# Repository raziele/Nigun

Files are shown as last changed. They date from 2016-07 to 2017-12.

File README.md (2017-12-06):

## Nigun (Melody)
RF down-converter for (but not only for) SDR

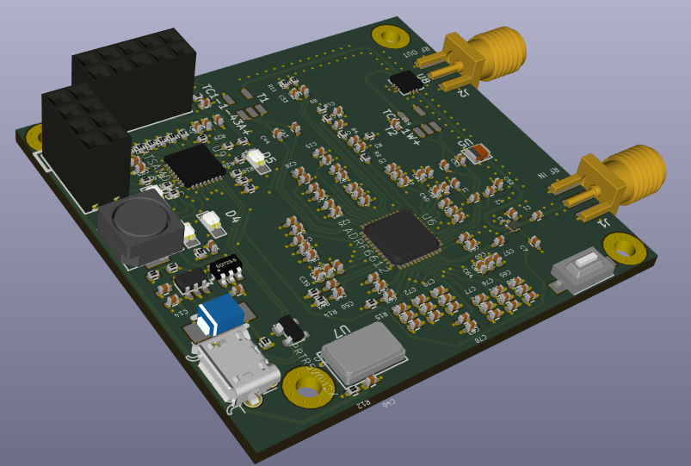
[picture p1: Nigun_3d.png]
NIGUN 3D model


## PURPOSE
Allow low-frequency SDR (mainly RTL-SDR) to recieve wireless signals in frequencies higher than 1500MHz
Nigun is platform-independant, so it can be paired with other devices such as YARD stick ONE and PandwaRF too!

## MAIN PROPERTIES
* Dynamic LO - LO will be determined by the user and programmed by the MCU
* Almost no filtering - will leave this challenge outside of this project scope
* Power up and programming via micro-usb connector. Should be able to power up from a USB power-pack (but probably not from a computer port)
* Highest RF frequency will be 3GHz
* Product also features a VCO for signal-generation purposes. VCO support should be 200-2700MHz

## DESIGN DETAILS
Can be found currently on http://slides.com/raziele/software-define-radio-4-5-6-7-8#/
All details should be updated here in the near future

## CURRENT STATUS
2017-05: Finished PCB design. Working on some finishing but I should order first batch during June

## CREDITS
* All those who were patient enough to teach, review, and answer my endless questions
* Michele Perla and his HACK project - for the Atmel SAMD21E reference design

## LICENSE
I haven't dealt with the licensing part yet, though it will probably be under CERN OHL v. 1.2.
For now, please contact me for any licensing request.

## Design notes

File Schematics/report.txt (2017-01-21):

Info: Reading netlist file "/Users/raziele/MyReps/Nigun/Schematics/Nigun.net".

Info: Using references to match components and footprints.

Info: Checking netlist component footprint "C1:/57E83FF1:Capacitors_SMD:C_0805_HandSoldering".

Info: Checking netlist component footprint "C2:/583F48BA:Capacitors_SMD:C_0805_HandSoldering".

Info: Checking netlist component footprint "C3:/583F48D7:Capacitors_SMD:C_0805_HandSoldering".

Info: Checking netlist component footprint "C4:/583F075F:Capacitors_SMD:C_0805_HandSoldering".

Info: Checking netlist component footprint "C5:/583F48C6:Capacitors_SMD:C_0805_HandSoldering".

Info: Checking netlist component footprint "C6:/57E9A56F:Capacitors_SMD:C_0805_HandSoldering".

Info: Checking netlist component footprint "C7:/57E843B4:Capacitors_SMD:C_0805_HandSoldering".

Info: Checking netlist component footprint "C8:/57E841A6:Capacitors_SMD:C_0805_HandSoldering".

Info: Checking netlist component footprint "C9:/583F083D:Capacitors_SMD:C_0805_HandSoldering".

Info: Checking netlist component footprint "C10:/584D4817:Capacitors_SMD:C_0805_HandSoldering".

Info: Checking netlist component footprint "C11:/583F48C0:Capacitors_SMD:C_0805_HandSoldering".

Info: Checking netlist component footprint "C12:/57E9A509:Capacitors_SMD:C_0805_HandSoldering".

Info: Checking netlist component footprint "C13:/583F0F91:Capacitors_SMD:C_0805_HandSoldering".

Info: Checking netlist component footprint "C14:/584FD6C7:Capacitors_SMD:C_0805_HandSoldering".

Info: Checking netlist component footprint "C15:/583F0F97:Capacitors_SMD:C_0805_HandSoldering".

Info: Checking netlist component footprint "C16:/57E9A3DC:Capacitors_SMD:C_0805_HandSoldering".

Info: Checking netlist component footprint "C17:/583F119E:Capacitors_SMD:C_0805_HandSoldering".

Info: Checking netlist component footprint "C18:/57E9A2BC:Capacitors_SMD:C_0805_HandSoldering".

Info: Checking netlist component footprint "C19:/583F11A4:Capacitors_SMD:C_0805_HandSoldering".

Info: Checking netlist component footprint "C20:/584D4E57:Capacitors_SMD:C_0805_HandSoldering".

Info: Checking netlist component footprint "C21:/583E122C:Capacitors_SMD:C_0805_HandSoldering".

Info: Checking netlist component footprint "C22:/583F0651:Capacitors_SMD:C_0805_HandSoldering".

Info: Checking netlist component footprint "C23:/583F11B2:Capacitors_SMD:C_0805_HandSoldering".

Info: Checking netlist component footprint "C24:/583E1238:Capacitors_SMD:C_0805_HandSoldering".

Info: Checking netlist component footprint "C25:/583F11B8:Capacitors_SMD:C_0805_HandSoldering".

Info: Checking netlist component footprint "C26:/584FEA40:Capacitors_SMD:C_0805_HandSoldering".

Info: Checking netlist component footprint "C27:/583E1232:Capacitors_SMD:C_0805_HandSoldering".

Info: Checking netlist component footprint "C28:/583F13C7:Capacitors_SMD:C_0805_HandSoldering".

Info: Checking netlist component footprint "C29:/583E22FC:Capacitors_SMD:C_0805_HandSoldering".

Info: Checking netlist component footprint "C30:/583E2AA4:Capacitors_SMD:C_0805_HandSoldering".

Info: Checking netlist component footprint "C31:/584238B5:Capacitors_SMD:C_0805_HandSoldering".

Info: Checking netlist component footprint "C32:/58713B34:Capacitors_SMD:C_0805_HandSoldering".

Info: Checking netlist component footprint "C33:/58713B22:Capacitors_SMD:C_0805_HandSoldering".

Info: Checking netlist component footprint "C34:/583E2308:Capacitors_SMD:C_0805_HandSoldering".

Info: Checking netlist component footprint "C35:/583E2AB0:Capacitors_SMD:C_0805_HandSoldering".

Info: Checking netlist component footprint "C36:/583F13CD:Capacitors_SMD:C_0805_HandSoldering".

Info: Checking netlist component footprint "C37:/584238BB:Capacitors_SMD:C_0805_HandSoldering".

Info: Checking netlist component footprint "C38:/583E2302:Capacitors_SMD:C_0805_HandSoldering".

Info: Checking netlist component footprint "C39:/583E2AAA:Capacitors_SMD:C_0805_HandSoldering".

Info: Checking netlist component footprint "C40:/5842214D:Capacitors_SMD:C_0805_HandSoldering".

Info: Checking netlist component footprint "C41:/58422153:Capacitors_SMD:C_0805_HandSoldering".

Info: Checking netlist component footprint "C42:/584C6A6C:Capacitors_SMD:C_0805_HandSoldering".

Info: Checking netlist component footprint "C43:/57F00F62:Capacitors_SMD:C_0805_HandSoldering".

Info: Checking netlist component footprint "C44:/57F00FE1:Capacitors_SMD:C_0805_HandSoldering".

Info: Checking netlist component footprint "C45:/584C6A66:Capacitors_SMD:C_0805_HandSoldering".

Info: Checking netlist component footprint "C46:/5843E0ED:Capacitors_SMD:C_0805_HandSoldering".

Info: Checking netlist component footprint "C47:/58447686:Capacitors_SMD:C_0805_HandSoldering".

Info: Checking netlist component footprint "C48:/58442CFE:Capacitors_SMD:C_0805_HandSoldering".

Info: Checking netlist component footprint "C49:/584472FC:Capacitors_SMD:C_0805_HandSoldering".

Info: Checking netlist component footprint "C50:/58442D04:Capacitors_SMD:C_0805_HandSoldering".

Info: Checking netlist component footprint "C51:/58432953:Capacitors_SMD:C_0805_HandSoldering".

Info: Checking netlist component footprint "C52:/58432DBA:Capacitors_SMD:C_0805_HandSoldering".

Info: Checking netlist component footprint "C53:/58442CF8:Capacitors_SMD:C_0805_HandSoldering".

Info: Checking netlist component footprint "C54:/57E999E3:Capacitors_SMD:C_0805_HandSoldering".

Info: Checking netlist component footprint "C55:/57E98EB0:Capacitors_SMD:C_0805_HandSoldering".

Info: Checking netlist component footprint "C56:/58445430:Capacitors_SMD:C_0805_HandSoldering".

Info: Checking netlist component footprint "C57:/584363BE:Capacitors_SMD:C_0805_HandSoldering".

Info: Checking netlist component footprint "C58:/57E99A47:Capacitors_SMD:C_0805_HandSoldering".

Info: Checking netlist component footprint "C59:/57E84808:Capacitors_SMD:C_0805_HandSoldering".

Info: Checking netlist component footprint "C60:/57E84838:Capacitors_SMD:C_0805_HandSoldering".

Info: Checking netlist component footprint "C61:/57E935EB:Capacitors_SMD:C_0805_HandSoldering".

Info: Checking netlist component footprint "C62:/583EE8B3:Capacitors_SMD:C_0805_HandSoldering".

Info: Checking netlist component footprint "C63:/583EE4D7:Capacitors_SMD:C_0805_HandSoldering".

Info: Checking netlist component footprint "C64:/57E93634:Capacitors_SMD:C_0805_HandSoldering".

Info: Checking netlist component footprint "C65:/583EE8B9:Capacitors_SMD:C_0805_HandSoldering".

Info: Checking netlist component footprint "C66:/583EE4DD:Capacitors_SMD:C_0805_HandSoldering".

Info: Checking netlist component footprint "C67:/57E9357B:Capacitors_SMD:C_0805_HandSoldering".

Info: Checking netlist component footprint "C68:/583EE8AD:Capacitors_SMD:C_0805_HandSoldering".

Info: Checking netlist component footprint "C69:/583EE4D1:Capacitors_SMD:C_0805_HandSoldering".

Info: Checking netlist component footprint "C70:/57E957CA:Capacitors_SMD:C_0805_HandSoldering".

Info: Checking netlist component footprint "C71:/5868BBFF:Capacitors_SMD:C_0805_HandSoldering".

Info: Checking netlist component footprint "C72:/57E957D0:Capacitors_SMD:C_0805_HandSoldering".

Info: Checking netlist component footprint "C73:/57E957C4:Capacitors_SMD:C_0805_HandSoldering".

Info: Checking netlist component footprint "C74:/583EE3E5:Capacitors_SMD:C_0805_HandSoldering".

Info: Checking netlist component footprint "C75:/57E95932:Capacitors_SMD:C_0805_HandSoldering".

Info: Checking netlist component footprint "C76:/584444DF:Capacitors_SMD:C_0805_HandSoldering".

Info: Checking netlist component footprint "C77:/57E95890:Capacitors_SMD:C_0805_HandSoldering".

Info: Checking netlist component footprint "C78:/5868BBF8:Capacitors_SMD:C_0805_HandSoldering".

Info: Checking netlist component footprint "C79:/583EE3EB:Capacitors_SMD:C_0805_HandSoldering".

Info: Checking netlist component footprint "C80:/57E95938:Capacitors_SMD:C_0805_HandSoldering".

Info: Checking netlist component footprint "C81:/584444D9:Capacitors_SMD:C_0805_HandSoldering".

Info: Checking netlist component footprint "C82:/57E95896:Capacitors_SMD:C_0805_HandSoldering".

Info: Checking netlist component footprint "C83:/583EE3DF:Capacitors_SMD:C_0805_HandSoldering".

Info: Checking netlist component footprint "C84:/57E9592C:Capacitors_SMD:C_0805_HandSoldering".

Info: Checking netlist component footprint "C85:/57E9588A:Capacitors_SMD:C_0805_HandSoldering".

Info: Checking netlist component footprint "C86:/58689704:Capacitors_SMD:C_0805_HandSoldering".

Info: Checking netlist component footprint "C87:/5868A8B2:Capacitors_SMD:C_0805_HandSoldering".

Info: Checking netlist component footprint "C88:/5868B512:Capacitors_SMD:C_0805_HandSoldering".

Info: Checking netlist component footprint "C89:/586A85CB:Capacitors_SMD:C_0805_HandSoldering".

Info: Checking netlist component footprint "D1:/584D5C1E:Footprints:DO-214AA-SMB".

Info: Checking netlist component footprint "D2:/585FF29B:Footprints:LED_kingsbright".

Info: Checking netlist component footprint "D3:/585FBFEB:Footprints:LED_kingsbright".

Info: Checking netlist component footprint "D4:/585FA657:Footprints:LED_kingsbright".

Info: Checking netlist component footprint "D5:/585FBD17:Footprints:LED_kingsbright".

Info: Checking netlist component footprint "J1:/584D1F16:gsg-modules:USB-MICROB-FCI-10103592-EXT".

Info: Checking netlist component footprint "J2:/57E6B654:Microwave:SMA".

Info: Checking netlist component footprint "J3:/57F043B3:Microwave:SMA".

Info: Checking netlist component footprint "L1:/58431611:Capacitors_SMD:C_0805_HandSoldering".

Info: Checking netlist component footprint "L2:/58431826:Capacitors_SMD:C_0805_HandSoldering".

Info: Checking netlist component footprint "L3:/58509D80:Capacitors_SMD:C_0805_HandSoldering".

Info: Checking netlist component footprint "P1:/585ED4D4:gsg-modules:HEADER-2x4".

Info: Checking netlist component footprint "P2:/586AEFB2:gsg-modules:HEADER-2x5".

Info: Checking netlist component footprint "R1:/586BE86E:Resistors_SMD:R_0805_HandSoldering".

Info: Checking netlist component footprint "R2:/57E9B13E:Resistors_SMD:R_0805_HandSoldering".

Info: Checking netlist component footprint "R3:/57E9AD1E:Resistors_SMD:R_0805_HandSoldering".

Info: Checking netlist component footprint "R4:/57E9AC44:Resistors_SMD:R_0805_HandSoldering".

Info: Checking netlist component footprint "R5:/57E9A6CE:Resistors_SMD:R_0805_HandSoldering".

Info: Checking netlist component footprint "R6:/586001C1:Resistors_SMD:R_0805_HandSoldering".

Info: Checking netlist component footprint "R7:/584FEFC6:Resistors_SMD:R_0805_HandSoldering".

Info: Checking netlist component footprint "R8:/584FF487:Resistors_SMD:R_0805_HandSoldering".

Info: Checking netlist component footprint "R9:/57E9C18F:Resistors_SMD:R_0805_HandSoldering".

Info: Checking netlist component footprint "R10:/58713B3A:Resistors_SMD:R_0805_HandSoldering".

Info: Checking netlist component footprint "R11:/58713B28:Resistors_SMD:R_0805_HandSoldering".

Info: Checking netlist component footprint "R12:/5843E28B:Resistors_SMD:R_0805_HandSoldering".

Info: Checking netlist component footprint "R13:/5844768C:Resistors_SMD:R_0805_HandSoldering".

Info: Checking netlist component footprint "R14:/58447302:Resistors_SMD:R_0805_HandSoldering".

Info: Checking netlist component footprint "R15:/58446CA0:Resistors_SMD:R_0805_HandSoldering".

Info: Checking netlist component footprint "R16:/585FD759:Resistors_SMD:R_0805_HandSoldering".

Info: Checking netlist component footprint "R17:/58728DE1:Resistors_SMD:R_0805_HandSoldering".

Info: Checking netlist component footprint "R18:/586959B3:Resistors_SMD:R_0805_HandSoldering".

Info: Checking netlist component footprint "R19:/5844119C:Resistors_SMD:R_0805_HandSoldering".

Info: Checking netlist component footprint "R20:/586C6DAC:Resistors_SMD:R_0805_HandSoldering".

Info: Checking netlist component footprint "R21:/5869F309:Resistors_SMD:R_0805_HandSoldering".

Info: Checking netlist component footprint "R22:/5869FAFB:Resistors_SMD:R_0805_HandSoldering".

Info: Checking netlist component footprint "R23:/586A003D:Resistors_SMD:R_0805_HandSoldering".

Info: Checking netlist component footprint "R24:/5869FCAB:Resistors_SMD:R_0805_HandSoldering".

Info: Checking netlist component footprint "R25:/586A03AC:Resistors_SMD:R_0805_HandSoldering".

Info: Checking netlist component footprint "R26:/586AAB79:Resistors_SMD:R_0805_HandSoldering".

Info: Checking netlist component footprint "R27:/586AAD6A:Resistors_SMD:R_0805_HandSoldering".

Info: Checking netlist component footprint "R28:/586AAF2A:Resistors_SMD:R_0805_HandSoldering".

Info: Checking netlist component footprint "R29:/58729E41:Resistors_SMD:R_0805_HandSoldering".

Info: Checking netlist component footprint "R30:/585FCA0C:Resistors_SMD:R_0805_HandSoldering".

Info: Checking netlist component footprint "R31:/586AD1C2:Resistors_SMD:R_0805_HandSoldering".

Info: Checking netlist component footprint "R32:/5851BC62:Resistors_SMD:R_0805_HandSoldering".

Info: Checking netlist component footprint "SW1:/58518796:Footprints:Tactile_SW".

Info: Checking netlist component footprint "T1:/57F018D9:Footprints:AT224-1A".

Info: Checking netlist component footprint "T2:/5842EE7B:Footprints:AT224-1A".

Info: Checking netlist component footprint "U1:/586C0C97:hack-footprints:TSOP-6".

Info: Checking netlist component footprint "U2:/57E83EDF:gsg-modules:SKY13351-378LF".

Info: Checking netlist component footprint "U3:/584B2484:TO_SOT_Packages_SMD:SOT-223".

Info: Checking netlist component footprint "U4:/584C153A:gsg-modules:SOT25".

Info: Checking netlist component footprint "U5:/57F046EE:Footprints:CP_0805".

Info: Checking netlist component footprint "U6:/57DD9FC9:ADRF6612_LFCSP48:LFCSP48".

Info: Checking netlist component footprint "U7:/585055F4:Footprints:FOX924".

Info: Checking netlist component footprint "U8:/57E66FA6:Housings_DFN_QFN:QFN-12-1EP_3x3mm_Pitch0.5mm".

Info: Checking netlist component footprint "U9:/5866F3E5:QFN32:QFN32".

Error: Component 'D1' pad '2' not found in footprint 'Footprints:DO-214AA-SMB'

Error: Component 'D1' pad '1' not found in footprint 'Footprints:DO-214AA-SMB'

Error: Component 'J2' pad '3' not found in footprint 'Microwave:SMA'

Error: Component 'J2' pad '4' not found in footprint 'Microwave:SMA'

Error: Component 'J2' pad '5' not found in footprint 'Microwave:SMA'

Error: Component 'J3' pad '3' not found in footprint 'Microwave:SMA'

Error: Component 'J3' pad '4' not found in footprint 'Microwave:SMA'

Error: Component 'J3' pad '5' not found in footprint 'Microwave:SMA'

Error: Component 'SW1' pad '2' not found in footprint 'Footprints:Tactile_SW'

Error: Component 'T1' pad '6' not found in footprint 'Footprints:AT224-1A'

Error: Component 'T2' pad '6' not found in footprint 'Footprints:AT224-1A'

Error: Component 'U5' pad '~' not found in footprint 'Footprints:CP_0805'

Error: Component 'U5' pad '~' not found in footprint 'Footprints:CP_0805'

Error: Component 'U5' pad '~' not found in footprint 'Footprints:CP_0805'

Error: Component 'U9' pad '33' not found in footprint 'QFN32:QFN32'

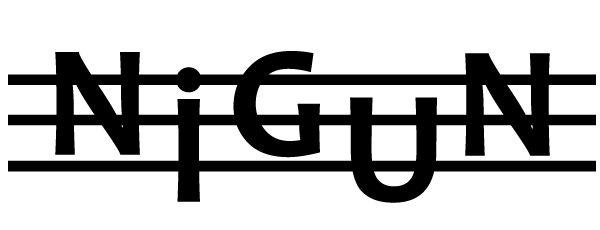
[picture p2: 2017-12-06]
Footprints/graphics/NIGUN.png

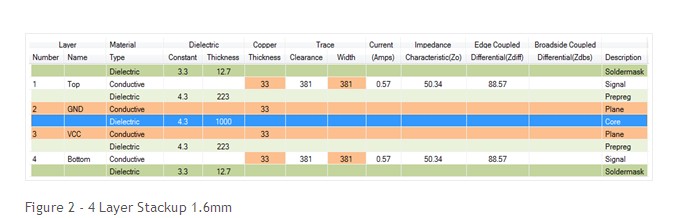
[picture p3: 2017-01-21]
Resources/PCBWay_stackup.jpg

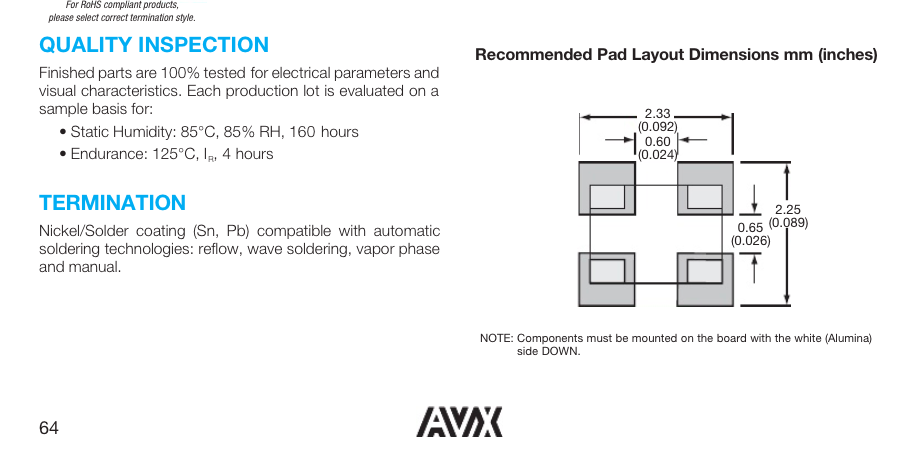
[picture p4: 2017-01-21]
Datasheets/CP0805_footprint.png

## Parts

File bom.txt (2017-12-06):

References	Qty	Description	Mouser cart
"C1, C43, C44, C9, C15, C19, C25, C36, C41, C37, C78, C42"	12	C 100pF Unpolarized capacitor 0402	
C6	1	C 1500pF Unpolarized capacitor 0402	
"C8, C7"	2	C 33pF Unpolarized capacitor 0402	
"C10, C20, C14, C26, C88"	5	C 1uF Unpolarized capacitor 0402	
C12	1	C 0.033uF Unpolarized capacitor 0402	
C16	1	C 560pF Unpolarized capacitor 0402	
C18	1	C 39pF Unpolarized capacitor 0402	
"C46, C58, C50, C48, C33, C32"	6	C 1000pF Unpolarized capacitor 0402	
"C53, C54, C59, C52, C47"	5	C 150pF Unpolarized capacitor 0402	
C57	1	C 22pF Unpolarized capacitor 0402	
C60	1	C 10nF Unpolarized capacitor 0402	
"C61, C63, C72, C79, C77, C56, C27, C38, C39, C76, C65, C64, C11, C49"	14	C 10pF Unpolarized capacitor 0402	
C62	1	C 10000pF Unpolarized capacitor 0402	
"C66, C74, C84, C82, C24, C34, C35, C81, C68, C67, C5, C51"	12	C 0.1uF Unpolarized capacitor 0402	
"C69, C75, C87, C86, C29, C30, C85, C71, C70, C22, C4, C13, C17, C23, C28, C3, C40, C31, C55, C83, C45, C90, C73"	23	C 10uF Unpolarized capacitor 0402	
"C89, C80, C91"	3	C Small 100nF Unpolarized capacitor 0402	
D1	1	D Schottky Small-RESCUE-Nigun Small DO-214AA-SMB	
D3	1	Led Small-RESCUE-Nigun Green LED kingsbright	
D4	1	Led Small-RESCUE-Nigun Blue LED kingsbright	
"D5, D2"	2	Led Small-RESCUE-Nigun Red LED kingsbright	
D6	1	PRTR5V0U2X SOT143B	V
J1	1	USB-MICRO-B FRAMATOME 10118194-0001LF	V
J2	1	SMA RF INPUT EDGELAUNCH	
J3	1	SMA RF OUTPUT EDGELAUNCH	
"L1, L2"	2	"L Small 330nH Inductor, small symbol C 0402"	
L3	1	"L Small 10uH Inductor, small symbol C 0603 HandSoldering"	
P1	1	"CONN 02X04 Connector, double row, 02x04 HEADER-2x4"	
P2	1	CONN SWD HEADER-2x5	
"R2, R9, R21, R22, R24, R23, R25, R1, R26, R27, R28, R20, R17"	13	R 0 Resistor 0402	
R3	1	R 910 Resistor 0402	
R4	1	R 1.8k Resistor 0402	
R5	1	R 20k Resistor 0402	
R7	1	R 3.92K Resistor 0402	
R8	1	R 2K Resistor 0402	
"R12, R15, R14, R13, R11, R10"	6	R 50 Resistor 0402	
"R18, R31"	2	"R Small 10k Resistor, small symbol 0402"	
"R19, R32, R30, R16, R6"	5	R 330 Resistor 0402	
R29	1	"R Small 1k Resistor, small symbol 0402"	
SW1	1	SW PUSH SMALL H Tactile	
T1	1	TC1-1-43A+ AT224-1A	alternative
T2	1	TC4-1W+ AT224-1A	alternative
U2	1	SKY13351 SKY13351-378LF	V
U3	1	"MIC5504-3.3YM5-TR 300[mA] Fixed Low Drop Positive Voltage Regulator, Output 3.3V, SOT223 SOT-23-5"	V
U4	1	AP7365-WG-7 SOT25	V
U5	1	LP0805A1119AS LP0805A0881AS CP 0805	Min.QTY
U6	1	ADRF6612 Wideband Mixer and VCO LFCSP48	V
U7	1	FOX924B-16.000 FOX924	V
U8	1	SKY13373 QFN-12-1EP 3x3mm Pitch0.5mm	V
U9	1	ATSAMD21E Atmel SAM D21 Cortex M0+ series QFN32	V
	146

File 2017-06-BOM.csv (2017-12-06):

References | Qty | Description | Mouser cart
C1, C43, C44, C9, C15, C19, C25, C36, C41, C37, C78, C42 | 12 | C 100pF Unpolarized capacitor 0402 | V
C6 | 1 | C 1500pF Unpolarized capacitor 0402 | V
C8, C7 | 2 | C 33pF Unpolarized capacitor 0402 | V
C10, C20, C14, C26, C88 | 5 | C 1uF Unpolarized capacitor 0402 | V
C12 | 1 | C 0.033uF Unpolarized capacitor 0402 | V
C16 | 1 | C 560pF Unpolarized capacitor 0402 | V
C18 | 1 | C 39pF Unpolarized capacitor 0402 | V
C46, C58, C50, C48, C33, C32 | 6 | C 1000pF Unpolarized capacitor 0402 | V
C53, C54, C59, C52, C47 | 5 | C 150pF Unpolarized capacitor 0402 | V
C57 | 1 | C 22pF Unpolarized capacitor 0402 | V
C60, C62 | 2 | C 10nF Unpolarized capacitor 0402 | V
C61, C63, C72, C79, C77, C56, C27, C38, C39, C76, C65, C64, C11, C49 | 14 | C 10pF Unpolarized capacitor 0402 | V
C66, C74, C84, C82, C24, C34, C35, C81, C68, C67, C5, C51, C89, C80, C91 | 15 | C 0.1uF Unpolarized capacitor 0402 | V
C69, C75, C87, C86, C29, C30, C85, C71, C70, C22, C4, C13, C17, C23, C28, C3, C40, C31, C55, C83, C45, C90, C73 | 23 | C 10uF Unpolarized capacitor 0402 | V
D1 | 1 | D Schottky Small-RESCUE-Nigun Small DO-214AA-SMB | V
D3 | 1 | Led Small-RESCUE-Nigun Green LED kingsbright | V
D4 | 1 | Led Small-RESCUE-Nigun Blue LED kingsbright | V
D5, D2 | 2 | Led Small-RESCUE-Nigun Red LED kingsbright | V
D6 | 1 | PRTR5V0U2X SOT143B | V
J1 | 1 | USB-MICRO-B FRAMATOME 10118194-0001LF | V
J2,J3 | 2 | SMA RF EDGELAUNCH | V
L1, L2 | 2 | L Small 330nH Inductor, small symbol C 0402 | V
L3 | 1 | L Small 10uH Inductor | V
P1 | 1 | CONN 02X04 Connector, double row, 02x04 HEADER-2x4 | V
P2 | 1 | CONN SWD HEADER-2x5 | V
R2, R9, R21, R22, R24, R23, R25, R1, R26, R27, R28, R20, R17 | 13 | R 0 Resistor 0402 | V
R3 | 1 | R 910 Resistor 0402 | V
R4 | 1 | R 1.8k Resistor 0402 | V
R5 | 1 | R 20k Resistor 0402 | V
R7 | 1 | R 3.92K Resistor 0402 | V
R8 | 1 | R 2K Resistor 0402 | V
R12, R15, R14, R13, R11, R10 | 6 | R 50 Resistor 0402 | V
R18, R31 | 2 | R Small 10k Resistor, small symbol 0402 | V
R19, R32, R30, R16, R6 | 5 | R 330 Resistor 0402 | V
R29 | 1 | R Small 1k Resistor, small symbol 0402 | V
SW1 | 1 | SW PUSH SMALL H Tactile | V
T1 | 1 | TC1-1-43A+ | alternative
T2 | 1 | TC4-1W+ | alternative
U2 | 1 | SKY13351 SKY13351-378LF | V
U3 | 1 | MIC5504-3.3YM5-TR 300[mA] Fixed Low Drop Positive Voltage Regulator, Output 3.3V, SOT223 SOT-23-5 | V
U4 | 1 | AP7365-WG-7 SOT25 | V
U5 | 1 | LP0805A1119AS LP0805A0881AS CP 0805 | Min.QTY
U6 | 1 | ADRF6612 Wideband Mixer and VCO LFCSP48 | V
U7 | 1 | FOX924B-16.000 FOX924 | V
U8 | 1 | SKY13373 QFN-12-1EP 3x3mm Pitch0.5mm | V
U9 | 1 | ATSAMD21E Atmel SAM D21 Cortex M0+ series QFN32 | V
 | 146
 | 46 |  | 43

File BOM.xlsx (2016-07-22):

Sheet: BOM
BOM LIST FOR DC2ME
# | FUNCTION | Number of pins | Insertion loss | Mf. PN | Mf. | Price\Unit | Amount | Total cost | Voltage
1 | RF switch | 6 |  | SKY13351-378LF (http://www.mouser.co.il/ProductDetail/Skyworks-Solutions-Inc/SKY13351-378LF/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) | SKYWORKS | $0.40 | 2 | $0.80 | 1.8-5
2 | Down-converter | 24 (17) |  | F1792NLGI (http://www.mouser.co.il/ProductDetail/IDT/F1792NLGI/) | IDT | $10.67 | 1 | $10.67 | 3.3
3 | VCO+PLL |  |  | ADF4350BCPZ-RL7 (http://www.mouser.co.il/ProductDetail/Analog-Devices/ADF4350BCPZ-RL7/) | AD | $12.02 | 1 | $12.02 | 3.3
4 | Filter?
5 | Voltage regulator
6 | MCU
7
8

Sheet: Frequencies
FREQUENCY CALCULATIONS
 | Low [MHz] | Center [MHz] | High [MHz] | Total [MHz] | RULES:
RF band | 1500 | 2100 | 2700 | 1200 | 1. Distance from LO to prevent LO leakage
Required IF band | 600 | 800 | 1000 | 400
RF Band |  |  | HIGH LO (LO-RF) | IMAGE (LO+IF)
LOW | MIDDLE | HIGH
1500 | 1550 | 1600 | 2350 | 3150
1600 | 1650 | 1700 | 2450 | 3250
1700 | 1750 | 1800 | 2550 | 3350
1800 | 1850 | 1900 | 2650 | 3450
1900 | 1950 | 2000 | 2750 | 3550
2000 | 2050 | 2100 | 2850 | 3650
2100 | 2150 | 2200 | 2950 | 3750
2200 | 2250 | 2300 | 3050 | 3850
2300 | 2350 | 2400 | 3150 | 3950
2400 | 2450 | 2500 | 3250 | 4050
2500 | 2550 | 2600 | 3350 | 4150
2600 | 2650 | 2700 | 3450 | 4250
2700 | 2750 | 2800 | 3550 | 4350
2800 | 2850 | 2900 | 3650 | 4450
2900 | 2950 | 3000 | 3750 | 4550

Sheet: Sheet3
IMAGE SINGALS CALCULATION
 | Low [MHz] | Center [MHz] | High [MHz] | Total [MHz]
RF band | 1500 | 2100 | 2700 | 1200
Required IF band | 600 | 800 | 1000 | 400

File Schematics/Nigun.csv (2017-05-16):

Reference | Type | Value | Quantity | Datasheet | manf# | Price
U6 | IC | ADRF6612 | 1
U8 | IC | SKY13373 | 1
J2 | Connector | RF_INPUT | 1
U2 | IC | SKY13351 | 1
C1 | Capacitor | 100pF | 1
C8 | Capacitor | 33pF | 1
C7 | Capacitor | 33pF | 1
C61 | Capacitor | 10pF | 1
C62 | Capacitor | 10000pF | 1
C69 | Capacitor | 10uF | 1
C63 | Capacitor | 10pF | 1
C66 | Capacitor | 0.1uF | 1
C75 | Capacitor | 10uF | 1
C72 | Capacitor | 10pF | 1
C74 | Capacitor | 0.1uF | 1
C87 | Capacitor | 10uF | 1
C79 | Capacitor | 10pF | 1
C84 | Capacitor | 0.1uF | 1
C86 | Capacitor | 10uF | 1
C77 | Capacitor | 10pF | 1
C82 | Capacitor | 0.1uF | 1
C57 | Capacitor | 22pF | 1
C56 | Capacitor | 10pF | 1
C60 | Capacitor | 10nF | 1
C18 | Capacitor | 39pF | 1
C16 | Capacitor | 560pF | 1
C12 | Capacitor | 0.033uF | 1
C6 | Capacitor | 1500pF | 1
R5 | Resistor | 20k | 1
R4 | Resistor | 1.8k | 1
R3 | Resistor | 910 | 1
R2 | Resistor | 0 | 1
R9 | Resistor | 0 | 1
C43 | Capacitor | 100pF | 1
C44 | Capacitor | 100pF | 1
T1 | Transformer | TC1-1-43A+ | 1
J3 | Connector | RF_OUTPUT | 1
U5 | IC | LP0805A0881AS | 1
C27 | Capacitor | 10pF | 1
C24 | Capacitor | 0.1uF | 1
C29 | Capacitor | 10uF | 1
C38 | Capacitor | 10pF | 1
C34 | Capacitor | 0.1uF | 1
C30 | Capacitor | 10uF | 1
C39 | Capacitor | 10pF | 1
C35 | Capacitor | 0.1uF | 1
C85 | Capacitor | 10uF | 1
C76 | Capacitor | 10pF | 1
C81 | Capacitor | 0.1uF | 1
C71 | Capacitor | 10uF | 1
C65 | Capacitor | 10pF | 1
C68 | Capacitor | 0.1uF | 1
C70 | Capacitor | 10uF | 1
C64 | Capacitor | 10pF | 1
C67 | Capacitor | 0.1uF | 1
C22 | Capacitor | 10uF | 1
C4 | Capacitor | 10uF | 1
C9 | Capacitor | 100pF | 1
C13 | Capacitor | 10uF | 1
C15 | Capacitor | 100pF | 1
C17 | Capacitor | 10uF | 1
C19 | Capacitor | 100pF | 1
C23 | Capacitor | 10uF | 1
C25 | Capacitor | 100pF | 1
C28 | Capacitor | 10uF | 1
C36 | Capacitor | 100pF | 1
C11 | Capacitor | 10pF | 1
C5 | Capacitor | 0.1uF | 1
C3 | Capacitor | 10uF | 1
C40 | Capacitor | 10uF | 1
C41 | Capacitor | 100pF | 1
C31 | Capacitor | 10uF | 1
C37 | Capacitor | 100pF | 1
T2 | IC | TC4-1W+ | 1
L1 | Inductor | 330nH | 1
L2 | Inductor | 330nH | 1
C53 | Capacitor | 150pF | 1
C54 | Capacitor | 150pF | 1
C59 | Capacitor | 150pF | 1
C46 | Capacitor | 1000pF | 1
R12 | Resistor | 50 | 1
R19 | Resistor | 330 | 1
C55 | Capacitor | 10uF | 1
C49 | Capacitor | 10pF | 1
C51 | Capacitor | 0.1uF | 1
C83 | Capacitor | 10uF | 1
C78 | Capacitor | 100pF | 1
C58 | Capacitor | 1000pF | 1
R15 | Resistor | 50 | 1
C50 | Capacitor | 1000pF | 1
R14 | Resistor | 50 | 1
C48 | Capacitor | 1000pF | 1
R13 | Resistor | 50 | 1
U3 | IC | MIC5504-3.3YM5-TR | 1
U4 | IC | AP7365-WG-7 | 1
C45 | Capacitor | 10uF | 1
C42 | Capacitor | 100pF | 1
J1 | Connector | USB-MICRO-B | 1
C10 | Capacitor | 1uF | 1
C20 | Capacitor | 1uF | 1
D1 | Diode | D_Schottky_Small | 1
C14 | Capacitor | 1uF | 1
C26 | Capacitor | 1uF | 1
R7 | Resistor | 3.92K | 1
R8 | Resistor | 2K | 1
U7 | IC | FOX924B-16.000 | 1
L3 | Inductor | 10uH | 1
SW1 | Button | SW_PUSH_SMALL_H | 1
R32 | Resistor | 330 | 1
P1 | Connector | CONN_02X04 | 1
D4 | LED | Blue | 1
D5 | LED | Red | 1
D3 | LED | Green | 1
R30 | Resistor | 330 | 1
R16 | Resistor | 330 | 1
D2 | LED | Red | 1
R6 | Resistor | 330 | 1
U9 | IC | ATSAMD21E | 1 |  | ATSAMD21E18A-MU
C88 | Capacitor | 1uF | 1
C89 | Capacitor | 100nF | 1
C90 | Capacitor | 10uF | 1
C80 | Capacitor | 100nF | 1
C73 | Capacitor | 10uF | 1
R18 | Resistor | 10k | 1
R21 | Resistor | 0 | 1
R22 | Resistor | 0 | 1
R24 | Resistor | 0 | 1
R23 | Resistor | 0 | 1
R25 | Resistor | 0 | 1
C91 | Capacitor | 100nF | 1
R31 | Resistor | 10k | 1
P2 | Connector | CONN_SWD | 1
R1 | Resistor | 0 | 1
R26 | Resistor | 0 | 1
R27 | Resistor | 0 | 1
R28 | Resistor | 0 | 1
R20 | Resistor | 0 | 1
C33 | Capacitor | 1000pF | 1
R11 | Resistor | 50 | 1
C32 | Capacitor | 1000pF | 1
R10 | Resistor | 50 | 1
R17 | Resistor | 0 | 1
C52 | Capacitor | 150pF | 1
C47 | Capacitor | 150pF | 1
D6 | Diode | PRTR5V0U2X | 1 | NXP Semiconductors |  | 0.38 USD
R29 | Resistor | 1k | 1

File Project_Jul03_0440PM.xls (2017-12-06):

NIGUN
Mouser No | Mfr. No | Manufacturer | Customer No | Description | RoHS | Lifecycle | Order Qty. | Price (USD) | Ext.: (USD)
556-ATSAMD20E17A-MU | ATSAMD20E17A-MU | Microchip |  | ARM Microcontrollers - MCU Cortex-M0+ 128KB FLASH 16KB SRAM | RoHS Compliant |  | 1 | $1.96 | $1.96
584-ADRF6612ACPZ-R7 | ADRF6612ACPZ-R7 | Analog Devices Inc. |  | RF Mixer Wideband Passive Mixer | RoHS Compliant | New At Mouser | 1 | $26.98 | $26.98
873-SKY13351-378LF | SKY13351-378LF | Skyworks |  | RF Switch ICs 20MHz-6.0GHz SPDT IL .35dB @ 2.45GHz | RoHS Compliant |  | 1 | $0.74 | $0.74
998-MIC5504-3.3YM5TR | MIC5504-3.3YM5-TR | Microchip |  | LDO Voltage Regulators Single 300mA LDO | RoHS Compliant |  | 1 | $0.12 | $0.12
621-AP7365-WG-7 | AP7365-WG-7 | Diodes Incorporated |  | LDO Voltage Regulators LDO ADJ OUT 600mA 35uA 2 to 6 Vin | RoHS Compliant |  | 1 | $0.52 | $0.52
559-FOX924B-16 | FOX924B-16.000 | Fox |  | TCXO Oscillators 16.0MHz 3.3Volts -30C +85C | RoHS Compliant |  | 1 | $2.34 | $2.34
873-SKY13373-460LF | SKY13373-460LF | Skyworks |  | RF Switch ICs .1-6.0GHz SP3T IL .45dB @ 2.5GHz | RoHS Compliant |  | 1 | $1.07 | $1.07
649-10118194-0001LF | 10118194-0001LF | FCI / Amphenol |  | USB Connectors 5P MICRO USB TYPE B RCPT W/ REAR PEGS | RoHS Compliant |  | 1 | $0.46 | $0.46
771-PRTR5V0U2X-T/R | PRTR5V0U2X,215 | Nexperia |  | ESD Suppressors / TVS Diodes 5.5V DUAL R-R ESD ULTRA LOW CAP | RoHS Compliant |  | 1 | $0.51 | $0.51
78-VS-MBRS130L-M35BT | VS-MBRS130L-M3/5BT | Vishay |  | Schottky Diodes & Rectifiers 1A 30V Single Die Schottky Rectifier | RoHS Compliant |  | 1 | $0.40 | $0.40
652-SRR0603-100ML | SRR0603-100ML | Bourns |  | Fixed Inductors 10uH 20% SMD 0603 | RoHS Compliant |  | 1 | $0.79 | $0.79
652-CE201210-R33J | CE201210-R33J | Bourns |  | Fixed Inductors 330nH 5% 1mm Multi Layer | RoHS Compliant |  | 1 | $0.10 | $0.10
506-FSMSM | FSMSM | TE Connectivity |  | Tactile Switches 3.5X6 SMT TACT TACT SWITCH | RoHS Compliant |  | 1 | $0.27 | $0.27
604-AP2012EC | AP2012EC | Kingbright |  | Standard LEDs - SMD RED WATER CLEAR | RoHS Compliant |  | 2 | $0.13 | $0.26
485-1865 | 1865 | Adafruit |  | RF Connectors / Coaxial Connectors SMA Connector for Thick PCBs | RoHS Compliant |  | 2 | $2.50 | $5.00
710-885012205055 | 885012205055 | Wurth Electronics |  | Multilayer Ceramic Capacitors MLCC - SMD/SMT WCAP-CSGP 100pF 0402 10% 50V MLCC | RoHS Compliant |  | 12 | $0.02 | $0.24
710-885012005055 | 885012005055 | Wurth Electronics |  | Multilayer Ceramic Capacitors MLCC - SMD/SMT WCAP-CSGP 10pF 0402 5% 50V MLCC | RoHS Compliant |  | 14 | $0.06 | $0.84
710-885012205061 | 885012205061 | Wurth Electronics |  | Multilayer Ceramic Capacitors MLCC - SMD/SMT WCAP-CSGP 1000pF 0402 10% 50V MLCC | RoHS Compliant |  | 6 | $0.02 | $0.12
710-885012105006 | 885012105006 | Wurth Electronics |  | Multilayer Ceramic Capacitors MLCC - SMD/SMT WCAP-CSGP 1F 0402 20% 6.3V MLCC | RoHS Compliant |  | 5 | $0.05 | $0.25
710-885012005010 | 885012005010 | Wurth Electronics |  | Multilayer Ceramic Capacitors MLCC - SMD/SMT WCAP-CSGP 33pF 0402 5% 10V MLCC | RoHS Compliant |  | 2 | $0.07 | $0.14
710-885012205056 | 885012205056 | Wurth Electronics |  | Multilayer Ceramic Capacitors MLCC - SMD/SMT WCAP-CSGP 150pF 0402 10% 50V MLCC | RoHS Compliant |  | 5 | $0.03 | $0.15
710-885012105016 | 885012105016 | Wurth Electronics |  | Multilayer Ceramic Capacitors MLCC - SMD/SMT WCAP-CSGP 100000pF 0402 20% 16V MLCC | RoHS Compliant |  | 5 | $0.02 | $0.10
791-0402X106M6R3CT | 0402X106M6R3CT | Walsin |  | Multilayer Ceramic Capacitors MLCC - SMD/SMT 10uF 20% 6.3 Volts 0402 | RoHS Compliant |  | 23 | $0.10 | $2.30
710-885012205067 | 885012205067 | Wurth Electronics |  | Multilayer Ceramic Capacitors MLCC - SMD/SMT WCAP-CSGP 10000pF 0402 10% 50V MLCC | RoHS Compliant |  | 2 | $0.02 | $0.04
603-RC0402JR-070RL | RC0402JR-070RL | Yageo |  | Thick Film Resistors - SMD ZERO OHM JUMPER | RoHS Compliant |  | 13 | $0.009 | $0.12
81-LQB15NNR33M10D | LQB15NNR33M10D | Murata |  | Fixed Inductors 0402 330nH 300mA +/-20% | RoHS Compliant |  | 2 | $0.10 | $0.20
710-885012205062 | 885012205062 | Wurth Electronics |  | Multilayer Ceramic Capacitors MLCC - SMD/SMT WCAP-CSGP 1500pF 0402 10% 50V MLCC | RoHS Compliant |  | 1 | $0.03 | $0.03
710-885012205053 | 885012205053 | Wurth Electronics |  | Multilayer Ceramic Capacitors MLCC - SMD/SMT WCAP-CSGP 33000pF 0402 10% 25V MLCC | RoHS Compliant |  | 1 | $0.04 | $0.04
81-GRM155R71H561KA01 | GRM155R71H561KA01D | Murata |  | Multilayer Ceramic Capacitors MLCC - SMD/SMT 0402 560pF 50volts X7R 10% | RoHS Compliant |  | 1 | $0.10 | $0.10
603-RC0402JR-0750RL | RC0402JR-0750RL | Yageo |  | Thick Film Resistors - SMD | RoHS Compliant |  | 6 | $0.10 | $0.60
603-RC0402FR-07330RL | RC0402FR-07330RL | Yageo |  | Thick Film Resistors - SMD 330 OHM 1% | RoHS Compliant |  | 5 | $0.10 | $0.50
603-RC0402FR-0710KL | RC0402FR-0710KL | Yageo |  | Thick Film Resistors - SMD 10K OHM 1% | RoHS Compliant |  | 2 | $0.10 | $0.20
603-RC0402FR-071KL | RC0402FR-071KL | Yageo |  | Thick Film Resistors - SMD 1K OHM 1% | RoHS Compliant |  | 2 | $0.10 | $0.20
652-CR0402FX-2001GLF | CR0402-FX-2001GLF | Bourns |  | Thick Film Resistors - SMD 2K OHM 1% | RoHS Compliant By Exemption |  | 1 | $0.10 | $0.10
754-RR0510P-3921D | RR0510P-3921-D | Susumu |  | Thin Film Resistors - SMD 1/16W 3.92Kohm 0.5% 25ppm | RoHS Compliant |  | 1 | $0.10 | $0.10
71-CRCW040220K0FKEDH | CRCW040220K0FKEDHP | Vishay |  | Thick Film Resistors - SMD 0.2W 20Kohms 1% High Power AEC-Q200 | RoHS Compliant By Exemption |  | 1 | $0.17 | $0.17
71-CRCW04021K80FKEDH | CRCW04021K80FKEDHP | Vishay |  | Thick Film Resistors - SMD 0.2W 1.8Kohms 1% High Power AEC-Q200 | RoHS Compliant By Exemption |  | 1 | $0.20 | $0.20
660-SG73P1ETTP911J | SG73P1ETTP911J | KOA Speer |  | Thick Film Resistors - SMD 0.125W 910ohm 5% 200ppm Anti-Pulse | RoHS Compliant By Exemption |  | 1 | $0.21 | $0.21
81-GRM1555C1H390FA1D | GRM1555C1H390FA01D | Murata |  | Multilayer Ceramic Capacitors MLCC - SMD/SMT 0402 39pF 50volts C0G 1% | RoHS Compliant |  | 1 | $0.10 | $0.10
710-885012005057 | 885012005057 | Wurth Electronics |  | Multilayer Ceramic Capacitors MLCC - SMD/SMT WCAP-CSGP 22pF 0402 5% 50V MLCC | RoHS Compliant |  | 1 | $0.07 | $0.07
604-APHHS1005CGCK | APHHS1005CGCK | Kingbright |  | Standard LEDs - SMD GREEN WTR CLEAR 40mcd 574nm | RoHS Compliant |  | 1 | $0.24 | $0.24
604-APHHS1005QBCD | APHHS1005QBC/D | Kingbright |  | Standard LEDs - SMD Blue 470nm Water Clear | RoHS Compliant |  | 1 | $0.39 | $0.39
571-5-146258-2 | 5-146258-2 | TE Connectivity |  | Headers & Wire Housings 04 MODII HDR DRST B/A .100CL | RoHS Compliant |  | 1 | $0.16 | $0.16
571-5-146256-5 | 5-146256-5 | TE Connectivity |  | Headers & Wire Housings VT 2X05P .1" 230/110 15AU | RoHS Compliant |  | 1 | $1.25 | $1.25

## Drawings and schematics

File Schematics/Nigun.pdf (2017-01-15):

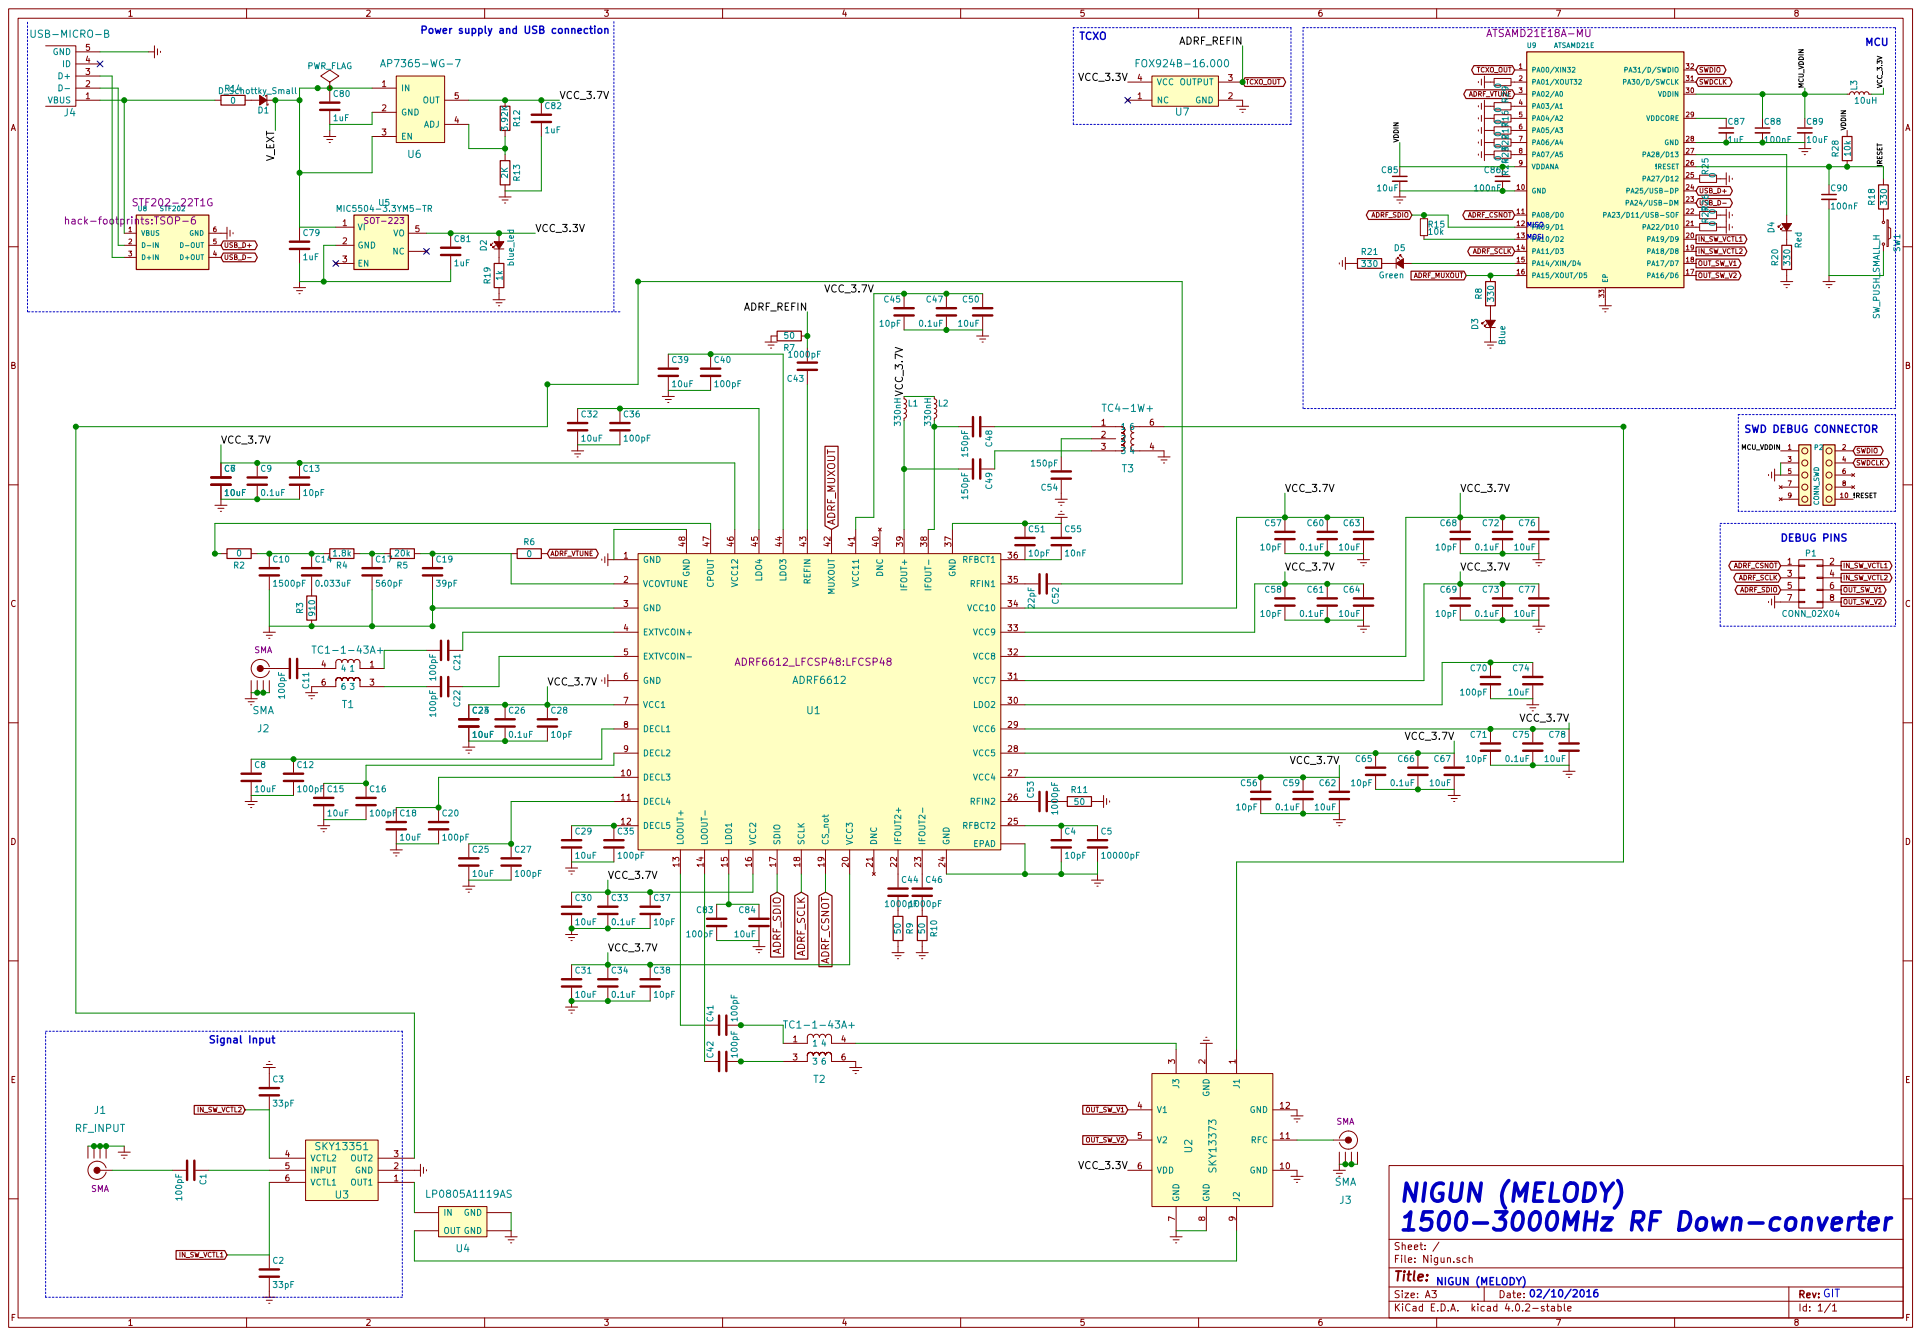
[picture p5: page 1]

!RESET MCU_VDDIN SWD DEBUG CONNECTOR

File: Nigun.sch Sheet: /

NIGUN (MELODY)

02/10/2016 | GIT

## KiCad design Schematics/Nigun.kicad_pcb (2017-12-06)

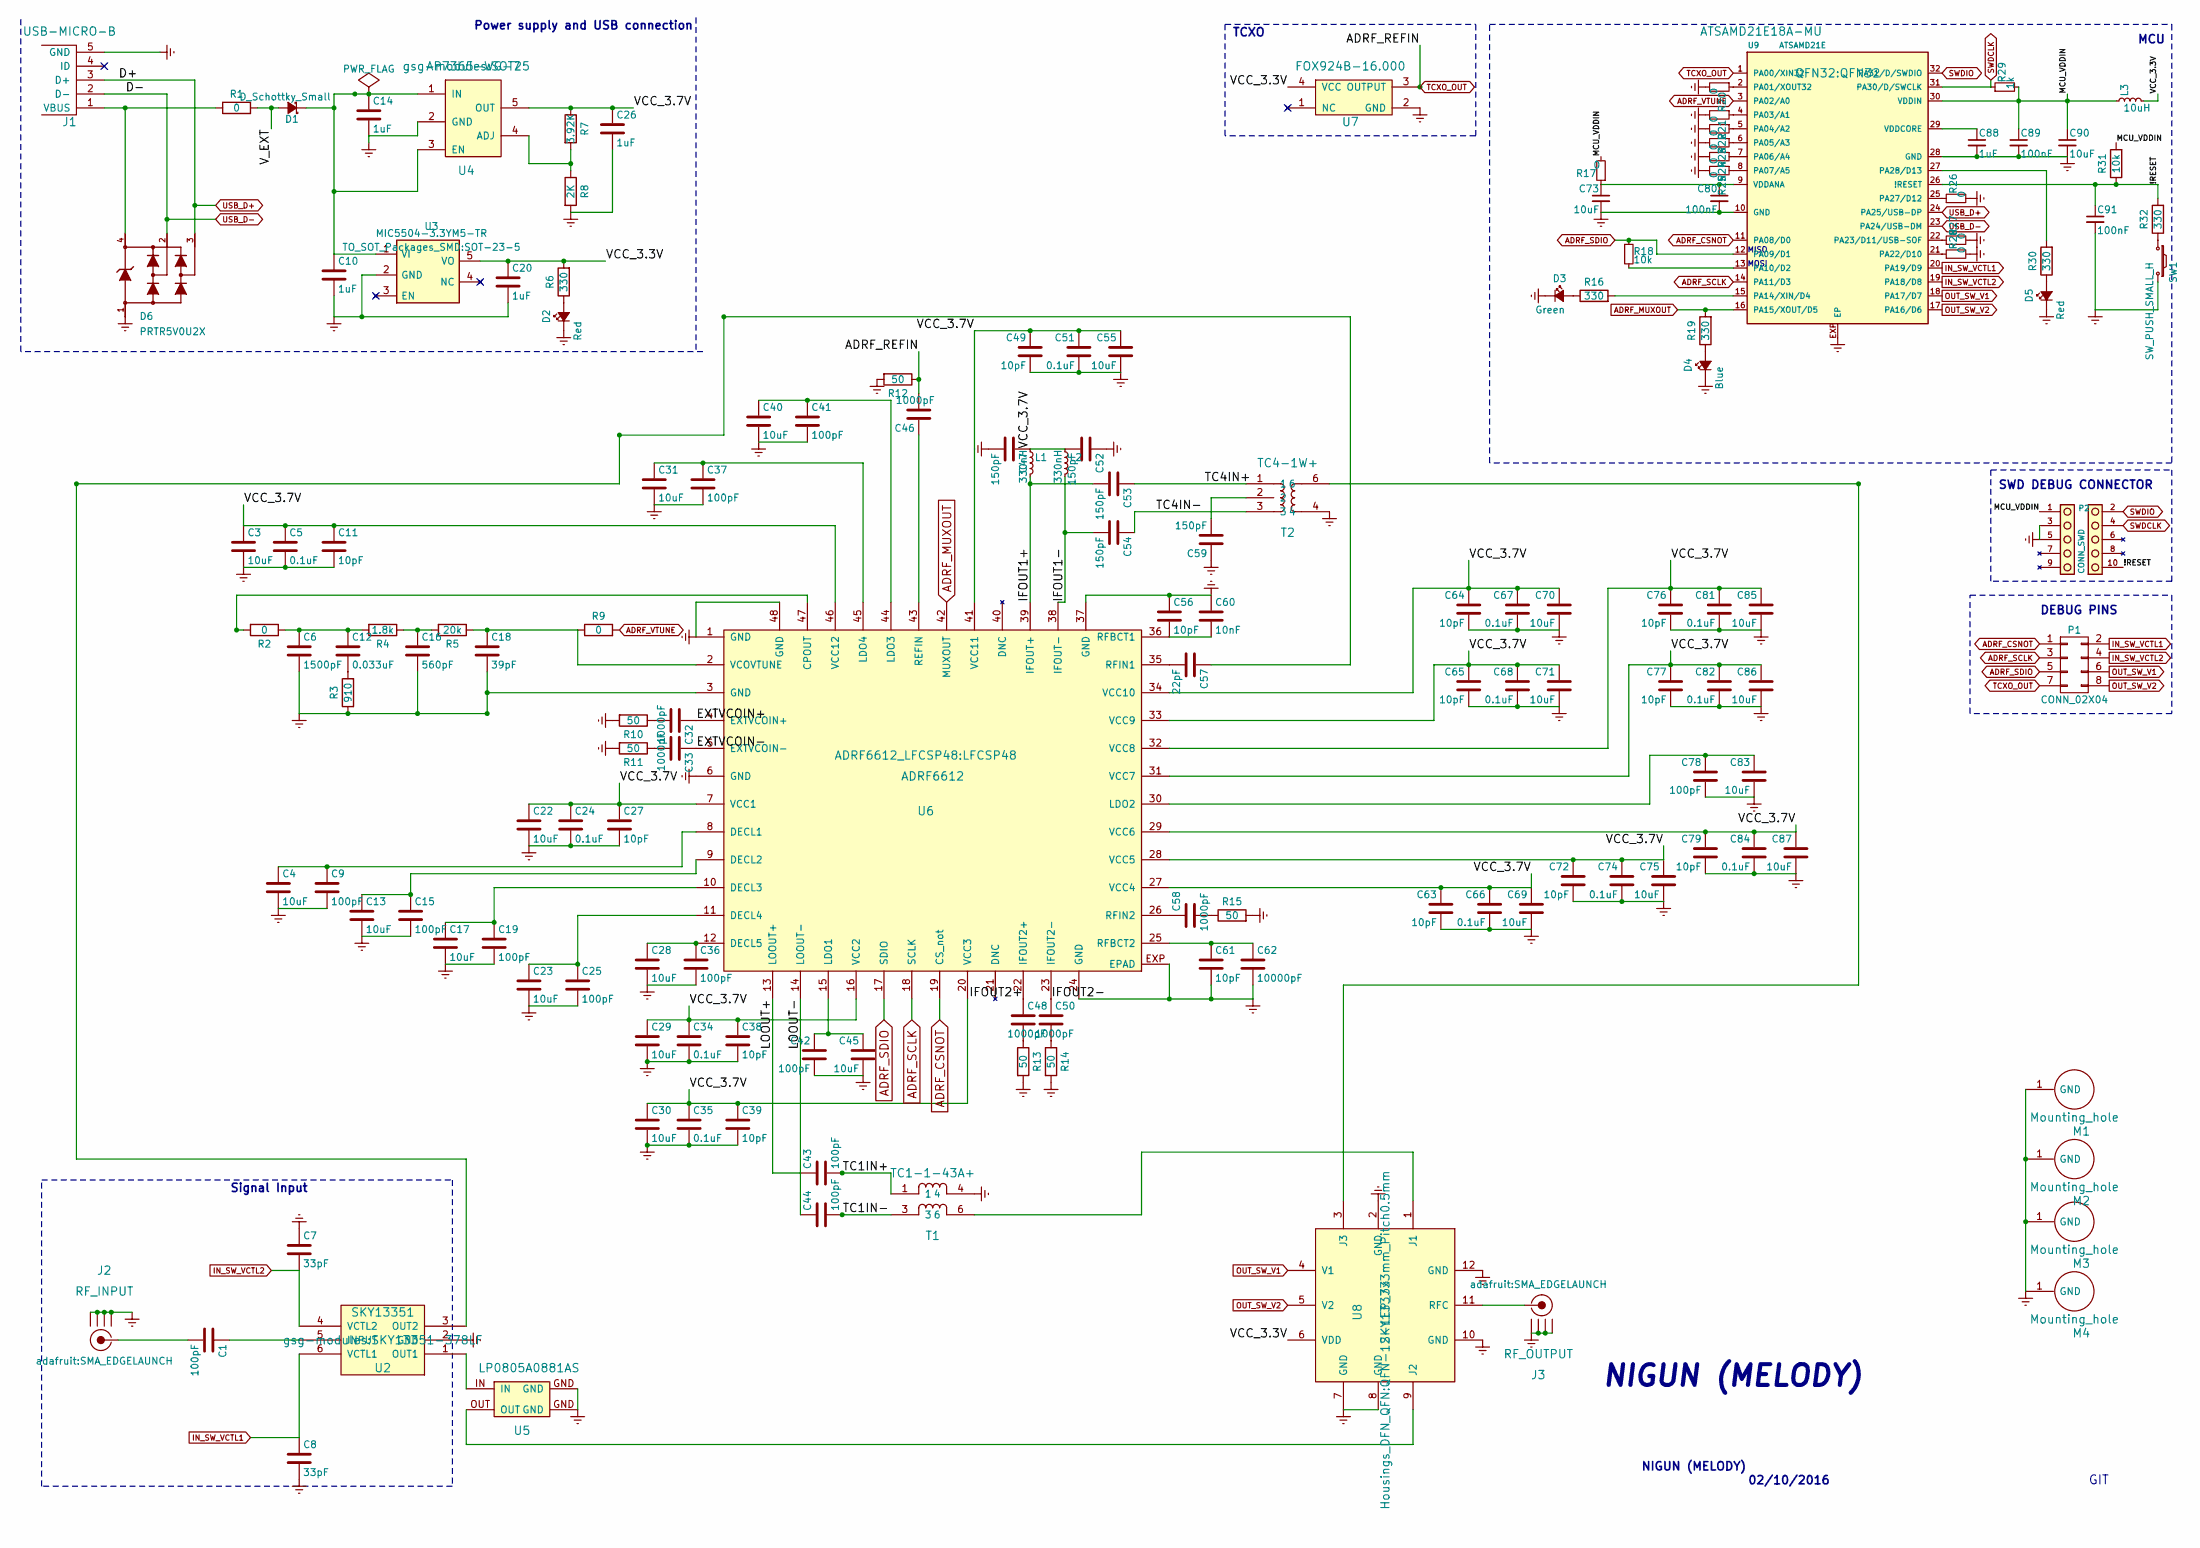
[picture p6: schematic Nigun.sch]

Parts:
C1, C9, C15, C19, C25, C36, C37, C41, C42, C43, C44, C78: 100pF; C_0402
C3, C4, C13, C17, C22, C23, C28, C29, C30, C31, C40, C45, C55, C69, C70, C71, C73, C75, C83, C85, C86, C87, C90: 10uF; C_0402
C5, C24, C34, C35, C51, C66, C67, C68, C74, C81, C82, C84: 0.1uF; C_0402
C6: 1500pF; C_0402
C7, C8: 33pF; C_0402
C10, C14, C20, C26, C88: 1uF; C_0402
C11, C27, C38, C39, C49, C56, C61, C63, C64, C65, C72, C76, C77, C79: 10pF; C_0402
C12: 0.033uF; C_0402
C16: 560pF; C_0402
C18: 39pF; C_0402
C32, C33, C46, C48, C50, C58: 1000pF; C_0402
C47, C52, C53, C54, C59: 150pF; C_0402
C57: 22pF; C_0402
C60: 10nF; C_0402
C62: 10000pF; C_0402
C80, C89, C91: 100nF; C_0402
D1: D_Schottky_Small; DO-214AA-SMB
D2, D5: Red; LED_kingsbright
D3: Green; LED_kingsbright
D4: Blue; LED_kingsbright
D6: PRTR5V0U2X; SOT143B
J1: USB-MICRO-B; FRAMATOME_10118194-0001LF
J2: RF_INPUT; SMA_EDGELAUNCH
J3: RF_OUTPUT; SMA_EDGELAUNCH
L1, L2: 330nH; C_0402
L3: 10uH; C_0603_HandSoldering
M1, M2, M3, M4: Mounting_hole; Mounting_hole_100mil
P1: CONN_02X04; HEADER-2x4
P2: CONN_SWD; HEADER-2x5
R1, R2, R9, R17, R20, R21, R22, R23, R24, R25, R26, R27, R28: 0; R_0402
R3: 910; R_0402
R4: 1.8k; R_0402
R5: 20k; R_0402
R6, R16, R19, R30, R32: 330; R_0402
R7: 3.92K; R_0402
R8: 2K; R_0402
R10, R11, R12, R13, R14, R15: 50; R_0402
R18, R31: 10k; R_0402
R29: 1k; R_0402
SW1: SW_PUSH_SMALL_H; Tactile_SW
T1: TC1-1-43A+; AT224-1A
T2: TC4-1W+; AT224-1A
U2: SKY13351; SKY13351-378LF
U3: MIC5504-3.3YM5-TR; SOT-23-5
U4: AP7365-WG-7; SOT25
U5: LP0805A0881AS; CP_0805
U6: ADRF6612; LFCSP48
U7: FOX924B-16.000; FOX924
U8: SKY13373; QFN-12-1EP_3x3mm_Pitch0.5mm
U9: ATSAMD21E; QFN32

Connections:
/!RESET: C91.1, P2.10 (nRESET), R31.1, R32.2, U9.26 (!RESET)
/EXTVCOIN+: C32.1, U6.4 (EXTVCOIN+)
/EXTVCOIN-: C33.1, U6.5 (EXTVCOIN-)
/IFOUT1+: C53.2, L1.2, U6.39 (IFOUT+)
/IFOUT1-: C54.2, L2.2, U6.38 (IFOUT-)
/IFOUT2+: C48.1, U6.22 (IFOUT2+)
/IFOUT2-: C50.1, U6.23 (IFOUT2-)
/LOOUT+: C43.1, U6.13 (LOOUT+)
/LOOUT-: C44.1, U6.14 (LOOUT-)
/MCU_VDDIN: C89.1, C90.1, L3.1, P2.1 (VTref), R17.2, R29.2, R31.2, U9.30 (VDDIN)
/TC1IN+: C43.2, T1.1
/TC1IN-: C44.2, T1.3
/TC4IN+: C53.1, T2.1
/TC4IN-: C54.1, T2.3
/VCC_3.3V: C20.1, L3.2, R6.2, U3.5 (VO), U7.4 (VCC), U8.6 (VDD)
/VCC_3.7V: C3.1, C5.1, C11.1, C22.1, C24.1, C26.1, C27.1, C29.1, C30.1, C34.1, C35.1, C38.1, C39.1, C47.1, C49.1, C51.1, C52.2, C55.1, C63.1, C64.1, C65.1, C66.1, C67.1, C68.1, C69.1, C70.1, C71.1, C72.1, C74.1, C75.1, C76.1, C77.1, C79.1, C81.1, C82.1, C84.1, C85.1, C86.1, C87.1, L1.1, L2.1, R7.1, U4.5 (OUT), U6.7 (VCC1), U6.16 (VCC2), U6.20 (VCC3), U6.27 (VCC4), U6.28 (VCC5), U6.29 (VCC6), U6.31 (VCC7), U6.32 (VCC8), U6.33 (VCC9), U6.34 (VCC10), U6.41 (VCC11), U6.46 (VCC12)
/V_EXT: D1.2 (A), R1.2
ADRF_CSNOT: P1.1, U6.19 (CS_not), U9.11 (PA08/D0)
ADRF_MUXOUT: R19.2, U6.42 (MUXOUT), U9.16 (PA15/XOUT/D5)
ADRF_SCLK: P1.3, U6.18 (SCLK), U9.14 (PA11/D3)
ADRF_SDIO: P1.5, R18.1, U6.17 (SDIO), U9.12 (PA09/D1)
ADRF_VTUNE: R9.2, U9.3 (PA02/A0)
Earth: C3.2, C4.2, C5.2, C6.2, C7.1, C8.2, C9.2, C10.2, C11.2, C13.2, C14.2, C15.2, C16.2, C17.2, C18.2, C19.2, C20.2, C22.2, C23.2, C24.2, C25.2, C26.2, C27.2, C28.2, C29.2, C30.2, C31.2, C34.2, C35.2, C36.2, C37.2, C38.2, C39.2, C40.2, C41.2, C42.2, C45.2, C47.2, C49.2, C51.2, C52.1, C55.2, C56.1, C59.1, C60.1, C61.2, C62.2, C63.2, C64.2, C65.2, C66.2, C67.2, C68.2, C69.2, C70.2, C71.2, C72.2, C73.2, C74.2, C75.2, C76.2, C77.2, C78.2, C79.2, C80.2, C81.2, C82.2, C83.2, C84.2, C85.2, C86.2, C87.2, C88.2, C89.2, C90.2, C91.2, D2.1 (K), D3.1 (K), D4.1 (K), D5.1 (K), D6.1, J1.5 (GND), J2.GND@ (GND1), J3.GND@ (GND1), M1.1, M2.1, M3.1, M4.1, P2.3 (GND), P2.5 (GND), R3.1, R8.2, R10.2, R11.2, R12.2, R13.2, R14.2, R15.2, R20.2, R21.2, R22.2, R23.2, R24.2, R25.2, R26.2, R27.2, R28.2, SW1.2, T1.4, T2.4, U2.2 (GND), U3.2 (GND), U4.2 (GND), U5.GND, U6.1 (GND), U6.3 (GND), U6.6 (GND), U6.24 (GND), U6.37 (GND), U6.48 (GND), U6.EXP (EPAD), U7.2 (GND), U8.2 (GND), U8.7 (GND), U8.8 (GND), U8.10 (GND), U8.12 (GND), U9.10 (GND), U9.28 (GND), U9.EXP (EP)
IN_SW_VCTL1: C8.1, P1.2, U2.6 (VCTL1), U9.20 (PA19/D9)
IN_SW_VCTL2: C7.2, P1.4, U2.4 (VCTL2), U9.19 (PA18/D8)
unnamed: C1.1, U2.5 (INPUT)
unnamed: C1.2, J2.P (RF)
unnamed: C4.1, C9.1, U6.8 (DECL1)
unnamed: C10.1, C14.1, D1.1 (C), U3.1 (VI), U4.1 (IN), U4.3 (EN)
unnamed: C6.1, C12.1, R2.1, R4.2
unnamed: C12.2, R3.2
unnamed: C13.1, C15.1, U6.9 (DECL2)
unnamed: C16.1, R4.1, R5.2
unnamed: C17.1, C19.1, U6.10 (DECL3)
unnamed: C18.1, R5.1, R9.1, U6.2 (VCOVTUNE)
unnamed: C23.1, C25.1, U6.11 (DECL4)
unnamed: C28.1, C36.1, U6.12 (DECL5)
unnamed: C31.1, C37.1, U6.45 (LDO4)
unnamed: C32.2, R10.1
unnamed: C33.2, R11.1
unnamed: C40.1, C41.1, U6.44 (LDO3)
unnamed: C42.1, C45.1, U6.15 (LDO1)
unnamed: C46.1, U6.43 (REFIN)
unnamed: C48.2, R13.1
unnamed: C50.2, R14.1
unnamed: C56.2, C60.2, U6.36 (RFBCT1)
unnamed: C57.1, U2.3 (OUT2)
unnamed: C57.2, U6.35 (RFIN1)
unnamed: C58.1, U6.26 (RFIN2)
unnamed: C58.2, R15.1
unnamed: C59.2, T2.2
unnamed: C61.1, C62.1, U6.25 (RFBCT2)
unnamed: C73.1, C80.1, R17.1, U9.9 (VDDANA)
unnamed: C78.1, C83.1, U6.30 (LDO2)
unnamed: C88.1, U9.29 (VDDCORE)
unnamed: D2.2 (A), R6.1
unnamed: D3.2 (A), R16.1
unnamed: D4.2 (A), R19.1
unnamed: D5.2 (A), R30.1
unnamed: D6.4, J1.1 (VBUS), R1.1
unnamed: J3.P (RF), U8.11 (RFC)
unnamed: R2.2, U6.47 (CPOUT)
unnamed: R7.2, R8.1, U4.4 (ADJ)
unnamed: R16.2, U9.15 (PA14/XIN/D4)
unnamed: R18.2, U9.13 (PA10/D2)
unnamed: R20.1, U9.2 (PA01/XOUT32)
unnamed: R21.1, U9.4 (PA03/A1)
unnamed: R22.1, U9.5 (PA04/A2)
unnamed: R23.1, U9.6 (PA05/A3)
unnamed: R24.1, U9.7 (PA06/A4)
unnamed: R25.1, U9.8 (PA07/A5)
unnamed: R26.1, U9.25 (PA27/D12)
unnamed: R27.1, U9.22 (PA23/D11/USB-SOF)
unnamed: R28.1, U9.21 (PA22/D10)
unnamed: R30.2, U9.27 (PA28/D13)
unnamed: R32.1, SW1.1
unnamed: T1.6, U8.1 (J1)
unnamed: T2.6, U8.3 (J3)
unnamed: U2.1 (OUT1), U5.IN
unnamed: U5.OUT, U8.9 (J2)
OUT_SW_V1: P1.6, U8.4 (V1), U9.18 (PA17/D7)
OUT_SW_V2: P1.8, U8.5 (V2), U9.17 (PA16/D6)
SWDCLK: P2.4 (SWDCLK), R29.1, U9.31 (PA30/D/SWCLK)
SWDIO: P2.2 (SWDIO), U9.32 (PA31/D/SWDIO)
TCXO_OUT: C46.2, P1.7, R12.1, U7.3 (OUTPUT), U9.1 (PA00/XIN32)
USB_D+: D6.3, J1.3 (D+), U9.24 (PA25/USB-DP)
USB_D-: D6.2, J1.2 (D-), U9.23 (PA24/USB-DM)

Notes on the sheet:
NIGUN (MELODY)
02/10/2016
GIT
Power supply and USB connection
Signal Input
MCU
MOSI
MISO
TCXO
SWD DEBUG CONNECTOR
DEBUG PINS

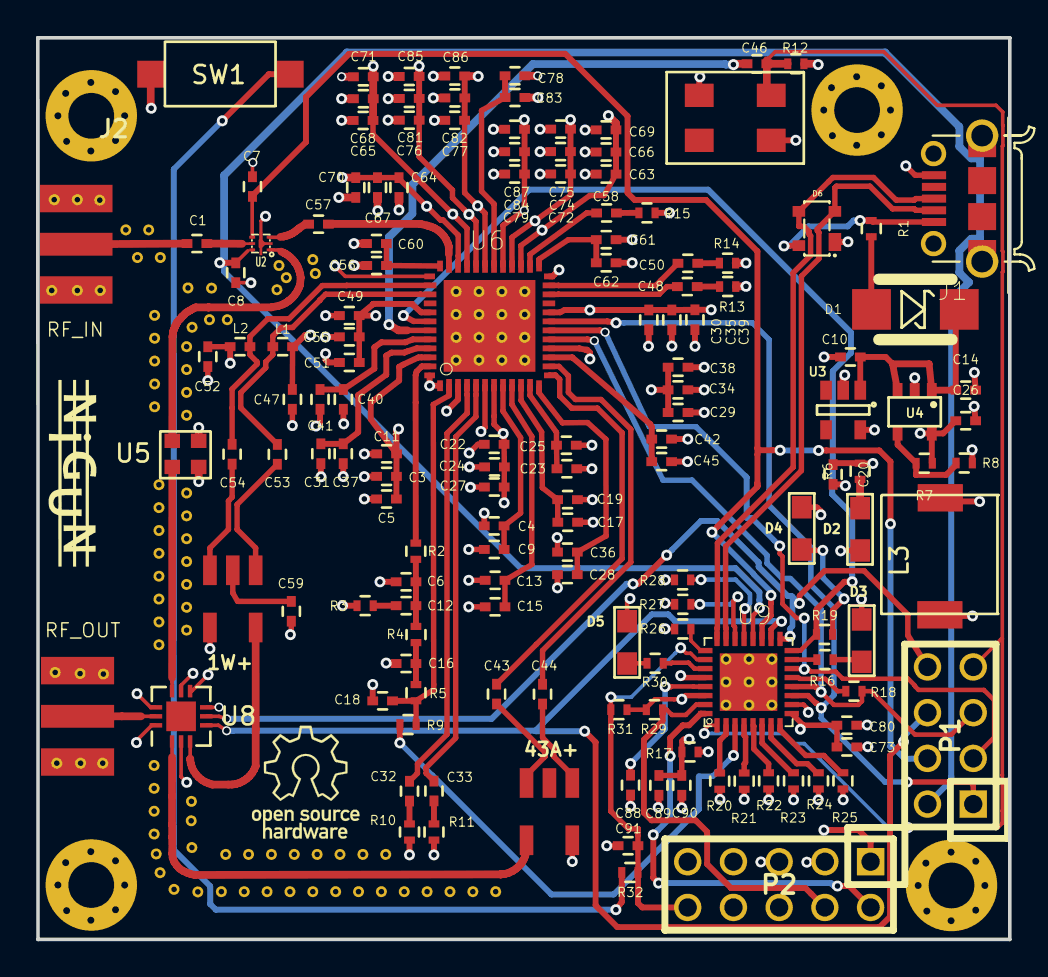
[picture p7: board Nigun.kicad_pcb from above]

Board: 4 copper layers, 54.0 x 50.1 mm, 151 parts (0 on the bottom side), 87 nets.

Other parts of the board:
LOGO1: OSHW; OSHW-LOGO

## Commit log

2016-07-22 Updated some info about potential components
    [BOM.xlsx]
2016-09-09 Added spur calcs
    [Mixers.xls, ProfessorsSpurSearchRev 1.xls]
2016-09-25 Adding main components datasheets and starting schematics
    [Mixers.xls, Nigun.kicad_pcb, Nigun.sch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]
2016-10-02 - Updated schematics - Added mini-circuits TC1-1-43A+ transformer to kicad library - Added AVX low-pass filter to lkicad ibrary
    [_saved_Nigun.sch]
2016-12-11 Schematics update
    [Nigun.sch]
2016-12-27 Almost finished schematics, based on ATSAMD20E MCU
    [Nigun.sch]
2017-01-15 Finished schematics
    [Nigun.sch, _saved_Nigun.sch, nigun_0603.kicad_pcb]
2017-01-21 replaced 45deg bent RF traces with curvy traces
    [Nigun.kicad_pcb, Nigun.sch, _saved_Nigun.sch]
2017-01-29 PCB design update - finished RF traces and 2 sides of 6612
    [Nigun.kicad_pcb, Nigun.sch]
2017-02-12 Changed ESD protection IC for USB bus
    [Nigun.sch]
2017-02-24 Place and route updates
    [Nigun.kicad_pcb, Nigun.sch]
2017-03-06 Finished front layer
    [Nigun.kicad_pcb, Nigun.sch]
2017-03-12 added large inductor at the MCU powe input
    [Nigun.kicad_pcb, _saved_Nigun.sch]
2017-05-09 Finished PCB editing, first version of gerber files
    [Nigun-Back.gbr, Nigun-Edge.Cuts.gbr, Nigun-F.Mask.gbr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]
2017-05-13 Added 3d model, updated components and readme
    [Nigun.kicad_pcb]
2017-05-16 Design update
    [Nigun.kicad_pcb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]
2017-05-16 Switched order of VCC and GND layers
    [1-click-bom.tsv, Nigun.csv, Nigun.kicad_pcb]
2017-05-17 Via size update and rearrange
    [Nigun.kicad_pcb]
2017-12-06 Finalized design for first prototype
    [2017-06-BOM.csv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]
